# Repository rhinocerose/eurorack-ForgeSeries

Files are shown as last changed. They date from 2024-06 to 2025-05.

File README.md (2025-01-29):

# Voltage Foundry Modular

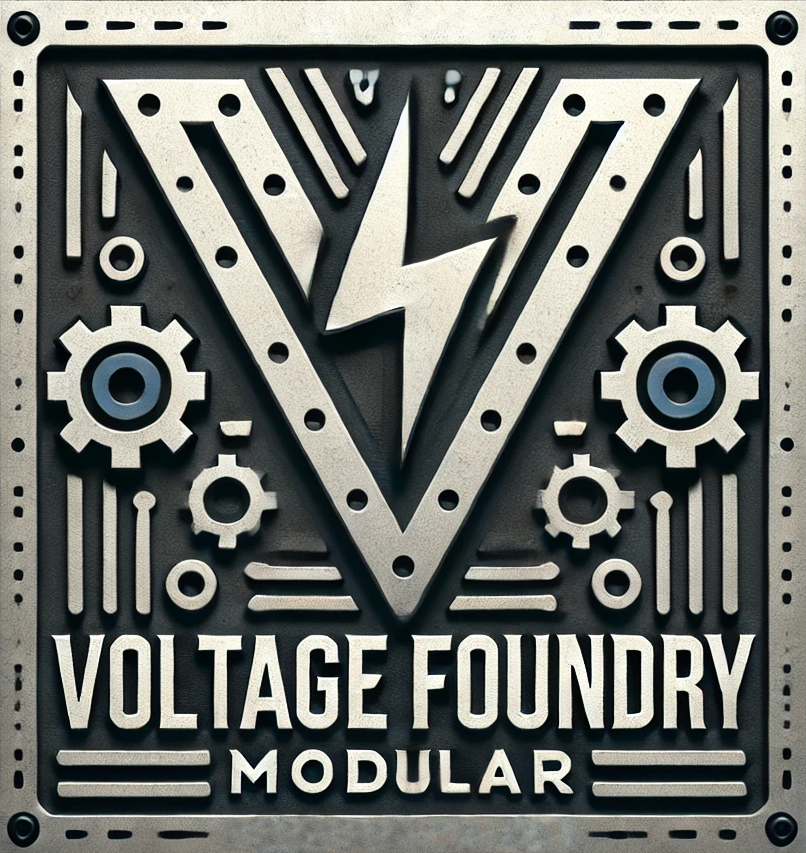
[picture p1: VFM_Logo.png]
Voltage Foundry Modular Logo


This repository hosts the **Forge** series of modules for the Eurorack format. The **Forge** series is a collection of firmwares developed for the Forge V1 platform based on the Seeeduino Xiao and MCP4725 DAC. The modules are designed to be easy to build and modify and be built with through-hole components. The firmware is based on the Arduino platform.

The concept is to have a generic hardware with a display, rotary encoder, trigger inputs and output, CV inputs and outputs allowing different modules by changing the firmware.

The module's core uses a Seeeduino Xiao (SAMD21/Cortex M0 chip) and a MCP4725 DAC.

This project currently provides the following modules:

- [ClockForge](./firmware-CLK/) - A Clock Generator with multiple features like tap tempo, clock division, Euclidean rhythm and more.
- [NoteForge](./firmware-DQ/) - A Dual Quantizer with selectable scales and root notes for each channel, octave shift and envelopes.
- [ForgeView](./firmware-SCP/) - A scope visualizer with dual-trace, trigger and more.

Modules can also be found on ModularGrid:

- [ClockForge](https://modulargrid.net/e/other-unknown-clockforge-by-voltage-foundry-modular)
- [NoteForge](https://modulargrid.net/e/other-unknown-NoteForge-by-voltage-foundry-modular)
- [ForgeView](https://modulargrid.net/e/other-unknown-forgeview-by-voltage-foundry-modular)

Each new module firmware will be in a separate folder which can be built and uploaded to the Seeeduino Xiao using PlatformIO.

## Production specifications

- Eurorack standard 3U 6HP size
- Power supply: 60mA
- Module depth: 42mm
- On-board converter from 12V to internal 5V (jumper selectable)

Power supply can be select from an on-board jumper where closing the the SEL with REG jumper, will take power from eurorack 12V supply and closing the SEL with BOARD jumper, will take power from 5V (requires 16 pin cable). It can also be powered by the USB-C jack on the Seeeduino Xiao.

## Project State

- ✅ - Working
- ❎ - Not tested
- 🚧 - Under development
- ❓ - Works with issues

| Firmware | Works | Remarks |
| --- | ----- | --- |
| Hardware | ✅ | |
| Clock Generator | ✅ | |
| Dual Quantizer | ✅ | |
| Scope | ❓ | Spectrum Analyzer not working yet |
| Dual Sequencer | 🚧 | |
| Sequencer | ❎ | Original firmware, not tested |
| Generative Sequencer | ❎ | Original firmware, not tested |

## Simulations

- Clock Generator: [Link](https://wokwi.com/projects/403851982905059329)

## Hardware and PCB

You can find the schematic and BOM in the [Hardware](./Hardware/) folder.
For the PCBs, the module has one main circuit PCB, one control circuit PCB and one panel PCB. The files are available in the [gerbers](./Hardware/gerbers/) directory.
You can order them on any common PCB manufacturing service, I used [JLCPCB](https://jlcpcb.com/). I made the circuits pcbs under 100mm to get the discount price.

If the panel size is not correctly detected by JLC manually put 30x128.5 mm.

When ordering the display module, make sure to choose an 0.96 I2C oled module that has the pinout specified as GND-VCC-SCL-SDA as opposed to VCC-GND-SCL-SDA (both exist and the latter won't work).

Also make sure you order a Seediuno XIAO (with a SAMD21/Cortex M0 chip) as opposed to the XIAO esp32c3 or the XIAO rp2040, those are different chips.

Display Module

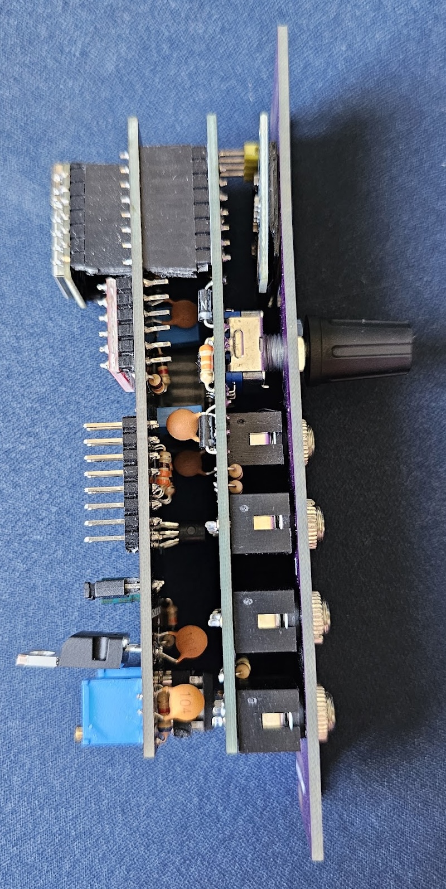
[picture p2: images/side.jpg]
Module Side


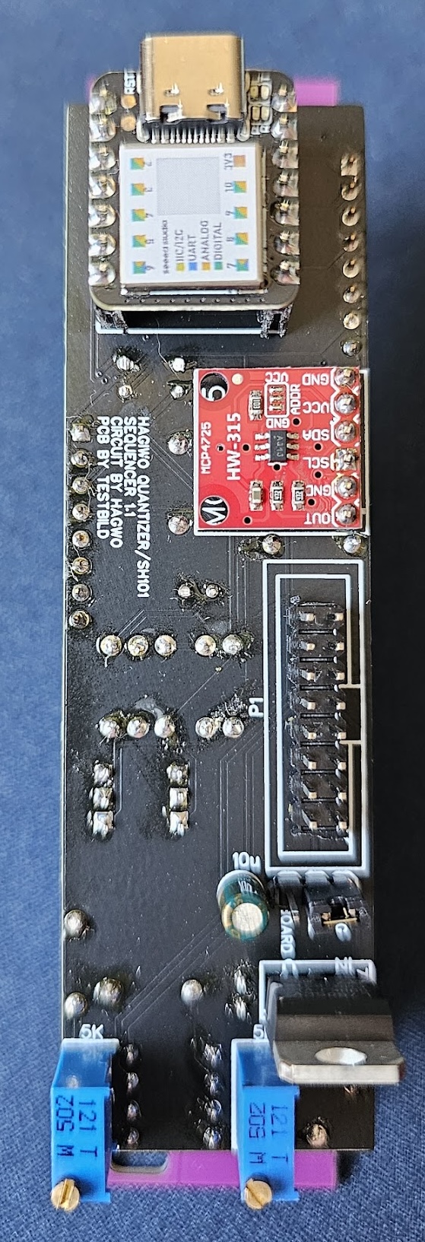
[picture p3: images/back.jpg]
Module Back


Pinout Diagram:

```text
|--------------------|
|                    |
|         O          |    1
|                    |
|   O           O    |  2   3
|                    |
|                    |
|   O           O    |  4   5
|                    |
|   O           O    |  6   7
|                    |
----------------------
```

- 1 - Trigger / Clock Input
- 2 - CV In 1
- 3 - CV In 2
- 4 - Digital Out 1
- 5 - Digital Out 2
- 6 - Analog Out 1 (Internal DAC)
- 7 - Analog Out 2 (External DAC)

## Assembly

When assembling, you can either use a header for the screen or solder it directly, as it is a litte too tall.
The 7805 voltage regulator is optional, if you do not want to use it, simply solder the SEL header on the back of the main pcb to BOARD instead of REG (meaning you bridge the connection to choose your 5v voltage source to either be 12 regulated to 5v, or a 5V connection of your rack power if you have it).

## Calibration

There are two things  in the circuit that need to be tuned for: The input resistor divider going from 5V to 3.3V, and the output opamp gain to go from 3.3 back to 5V.
I will provide a script to help with this and a detailed description in the future, but for now the short version is: Input resistors are compensated for in code with the AD_CH1_calb/AD_CH2_calb parameters. Output gain is adjusted using the trimmers on the main pcb.

Vin(5v) *(R21(33k)/R21(33k)+R19(18k) = Vout
5v:1 = Vout:a(AD_CH1_calb) (in my case AD_CH1_calb = 0.971)

3.3v to 5v(scale up)
5v/3.3v = 1.51515
0.51515 = 5k(adjustable)/6.8k

## Acknowledgements

The initial [hardware](./Hardware/) is based on Hagiwo 033 module. The quantizer base code is from the [original](https://note.com/solder_state/n/nb8b9a2f212a2) Hagiwo 033 Dual Quantizer and the updated thru-hole project by [Testbild-synth](https://github.com/Testbild-synth/HAGIWO-029-033-Eurorack-quantizer). Some ideas for the clock module were "taken" from the [LittleBen module](https://github.com/Quinienl/LittleBen-Firmware) from Quinie.nl and Pamela's Workout.

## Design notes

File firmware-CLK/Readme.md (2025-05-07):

# ClockForge: Crafting Time, One Pulse at a Time

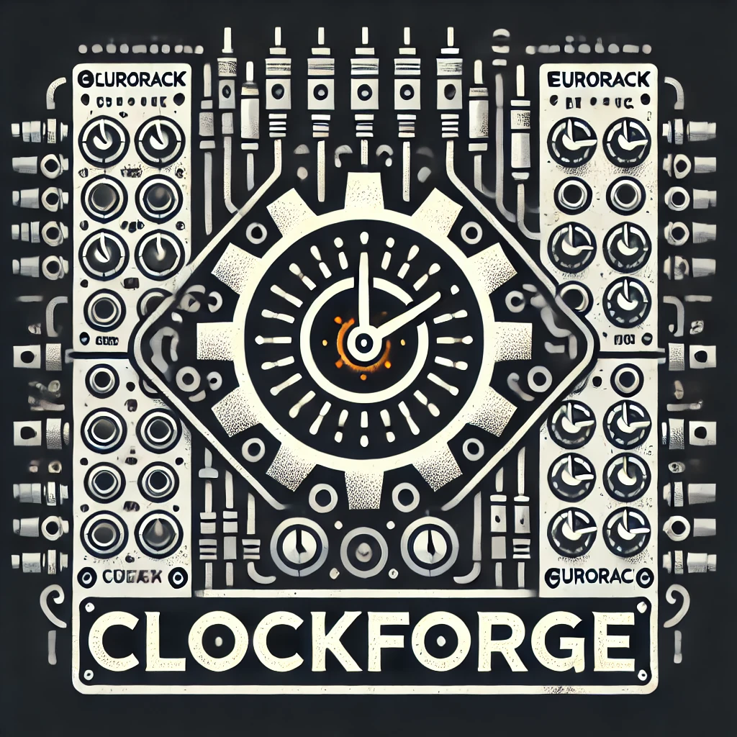
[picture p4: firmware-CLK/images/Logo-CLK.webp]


## Overview

ClockForge provides clock signals and waves for synchronizing and modulating other modules in your Eurorack system. It features a global BPM control, multiple clock outputs, adjustable clock multiplication and division per output, tap tempo functionality, sync to external clock sources, Euclidean rhythm generation, and custom swing patterns per output.

Part of the **Forge** series of modules which share a single hardware platform.

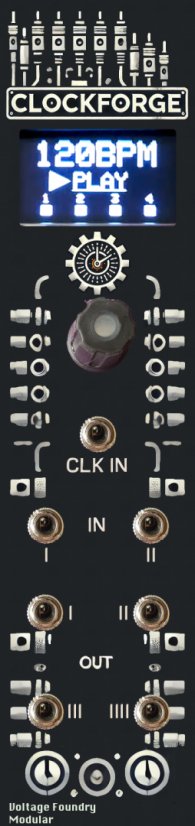
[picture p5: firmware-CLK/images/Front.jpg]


[ModularGrid]([https://](https://modulargrid.net/e/other-unknown-clockforge-by-voltage-foundry-modular))

## Features

- **Global BPM Control**: Set the global BPM for all outputs.
- **Multiple Clock Outputs**: Four clock outputs with individual settings.
- **Adjustable Clock Multiplication and Division**: Configure each output to multiply or divide the global BPM.
- **Output Waveform Generation**: Outputs 3 and 4 can generate different waveforms for modulation.
- **Pulse Probability**: Set the probability of a pulse occurring.
- **Euclidean Rhythm Generation**: Generate complex rhythms using Euclidean algorithm.
- **Custom Swing Patterns**: Apply swing to each output individually.
- **Sync to External Clock Sources**: Automatically adjust BPM based on an external clock signal.
- **Phase Shift**: Adjust the phase of the output in relation to the master clock.
- **Waveform Duty Cycle**: Adjust the pulse width of the clock signal.
- **External modulation**: Many parameters can be modulated by the CV inputs.
- **Tap Tempo Functionality**: Manually set the BPM by tapping a button.
- **Quantization**: Quantize the output wave or CV input to some scale and root note.
- **Save/Load Configuration**: Save and load up to 5 configurations.

## Configuration Parameters

The right side of the screen shows a navigation line to indicate the current position of the cursor in the menu. The navigation is not shown in the main (BPM) screen.

Whenever a parameter is changed, a small circle will be shown in the top-left corner of the screen. This indicates that the current settings were modified and not saved.

Due to encoder reads and screen update, expect some glitches in timing and waveform generation when changing parameters. The module will stabilize right after the parameter is set.

### Global Parameters

- **BPM**: Beats per minute, adjustable from 10 to 300.
- **Master Stop**: Stop or resume all outputs.

The small squares on main screen shows the status of each output. If the square is filled, the output is active. If the square is empty, the output is stopped.

### Output Parameters

Each of the four outputs can be individually configured with the following parameters:

- **Divider/Multiplier**: Set the clock multiplication or division ratio.
- **Output State**: Enable or disable the specific output.
- **Pulse Probability**: Probability of a pulse occurring.
- **Euclidean Enabled**: Enable or disable Euclidean rhythm generation.
- **Euclidean Steps**: Number of steps in the Euclidean pattern.
- **Euclidean Triggers**: Number of triggers in the Euclidean pattern.
- **Euclidean Rotation**: Rotate the Euclidean pattern.
- **Euclidean Pad**: Add empty steps to the end of the Euclidean pattern.
- **Swing Amount**: Adjust the swing amount for the output.
- **Swing Every**: Set the pulse interval for applying swing.
- **Phase Shift**: Adjust the phase of the output in relation to the master clock.
- **Duty Cycle**: Adjust the pulse width of the clock signal.
- **Level**: Set the output voltage level (only for CV outputs 3 and 4).
- **Offset**: Set the output voltage offset (only for CV outputs 3 and 4).
- **Waveform**: Select the waveform for outputs 3 and 4.
- **Quantization**: Quantize the output to a specific scale and root note.

## Operation

### Interface

- TRIG: Optional Clock input (0-5V)
- IN1, IN2: CV input to control internal parameters (0-5V)
- OUT 1 / 2: Clock Outputs 1 and 2 (0-5V)
- OUT 3 / 4: Clock Outputs 3 and 4 which are waveform capable (0-5V)

### Setting the BPM

1. Use the encoder to navigate to the BPM setting.
2. Push the encoder to enter edit mode.
3. Rotate the encoder to adjust the BPM value.
4. Press the encoder to exit edit mode.

### Global Play/Stop

With the **PLAY** or **STOP** word underlined, press the encoder button to stop or resume all outputs. The individual outputs can still be stopped or resumed individually and will remain in the last state set.

### Output clock division/multiplication

Outputs can be configured to multiply or divide the master clock. The default value is 1x which means the output will be in sync with the master clock. The outputs can be multiplied up to 32x or divided down to /128 with some triplets and dotted notes in between in the "1.5" and "3" division and multiplier values.

1. Navigate to the selected output.
2. Click the encoder to enter edit mode.
3. Use the encoder to select the desired divider value.
4. Click the encoder to exit edit mode.

### Output Play/Stop

Outputs can be stopped individually. When stopped, the output will not generate any pulses. When master stop is activated, all outputs will be stopped and when master play is resumed, any stopped output will be kept stopped.

1. Navigate to the selected output.
2. Click the encoder to set the output to ON or OFF

If the output wave type is set to "Play", the output will be true (high) when the master clock is running and false (low) when the master clock is stopped. This is useful for triggering other modules based on the master clock.

If the output wave type is set to "Reset", the output will trigger (high) when the master clock starts running. This is useful for resetting other modules based on the master clock.

### Pulse Probability

This is the percentage of probability that a pulse will be generated on the output. This is useful for creating random patterns or adding some variation to the output.

1. Navigate to the selected output.
2. Click the encoder to enter edit mode.
3. Use the encoder to select the desired pulse probability in percentage.
4. Click the encoder to exit edit mode.

### Euclidean Rhythm Configuration

Euclidean rhythms are made from an algorithm which takes a numbers of steps, triggers(HITS) which are active steps and rotation(RT) of this pattern and produces a rhythm based the on hits being as equidistant from each other as possible. See <https://en.wikipedia.org/wiki/Euclidean_rhythm> for more info.

Additional empty steps can be added to the pattern using the pad(PD) parameter. This is useful for creating more complex rhythms.

1. Navigate to the output selection item. Click the encoder and rotate to select the output to be edited. Click the encoder again to exit the output selection.
2. First setting enables or disables the Euclidean rhythm generation by clicking the encoder.
3. Select the Steps, Triggers and Rotation parameters, click the encoder to edit the values.
4. The pattern will be updated in real-time and displayed on the right of the screen. Euclidean rhythm allows up to 64 steps but only the first 47 are displayed. Rhythm steps are shown in columns, top to bottom, left to right.

The euclidean rhythm pulse is affected by the pulse probability setting.

### Swing Configuration

The outputs can have a swing pattern applied to them. The swing amount is in 1/96th of a note based on current BPM and the swing every is the interval between applying the swing. The swing amount can be set from 2/96th to 12/96th delay and the swing every from 1 to 16 pulses.

1. Navigate to the selected output. The first parameter to be edited is the swing amount.
2. Click the encoder to enter edit mode.
3. Use the encoder to select the desired swing amount.
4. Click the encoder to exit edit mode.
5. Navigate to the selected output, the second parameter to be edited is the swing every.
6. Click the encoder to enter edit mode.
7. Use the encoder to select the desired swing every value.
8. Click the encoder to exit edit mode.

### Output Phase Shift

Outputs can have their phase adjusted in percentage in relation to the master pulse. This allows for phase shifting the output in relation to the master clock. The default value is 0% which means the output is in phase with the master clock.
An adjstment of 50% will shift the output by half a pulse width which means that this output will hit in the upbeats of the master clock (or an output with a 0% phase shift).

Just be careful with phase wraps as shifting an output phase by more than 50% with a duty-cycle bigger than 50% can lead to unexpected triggers.

### Duty Cycle (pulse width)

Duty cycle or width is the percentage of the pulse that remains high or low. The default value is 50% which means the pulse high cycle has the same lenght as the low cycle. The duty cycle can be set from 1 to 99% where 1% will generate a very short pulse and 99% a very long high pulse.

The alternative waveforms generated by outputs 3 and 4 can also have their shape modified by the duty cycle parameter. For example, a 50% duty cycle (default) in the triangle wave output will generate a perfect triangle wave, setting the duty cycle to 1% will generate a sawtooth wave and setting it to 99% will generate an inverted sawtooth wave. The duty cycle also affects the envelopes by shortening or lengthening the decay time during the pulse.

1. Select the duty cycle parameter for the desired output. Click the encoder to enter edit mode.
2. Use the encoder to select the desired duty cycle value from 1 to 99%.
3. Click the encoder to exit edit mode.

### Output Level and Offset

Outputs 3 and 4 can output CV values so they support setting the output level and offset which ranges from 0 to 100% corresponding to 0 to 5V.

1. Navigate to the selected output. Click the encoder to enter edit mode.
2. Use the encoder to select the desired output level from 0 to 100% which corresponds to 0 to 5V.
3. Click the encoder to exit edit mode.

### Output Waveform

Outputs 1 and 2 only support square waveforms which could be used as triggers, gates, clocking, LFOs. etc.

Outputs 3 and 4 can be configured to alternative waveforms and envelopes.

They support the following:

- **Square**: A square wave with adjustable duty cycle, level and offset.
- **Triangle**: A triangle wave with adjustable duty cycle, level and offset.
- **Sawtooth**: A sawtooth wave with adjustable duty cycle, level and offset.
- **Sine**: A sine wave with adjustable duty cycle, level and offset.
- **Parabolic**: A parabolic wave with adjustable duty cycle, level and offset.
- **Logarithm Envelope**: A logarithm envelope (starts at 0% raising to 100%) with adjustable level and offset. Triggered by clock pulses.
- **Exponential Envelope**: An exponential envelope (starts at 0% raising to 100%) with adjustable level and offset. Triggered by clock pulses.
- **Inverted Logarithm Envelope**: An inverted logarithm envelope (starts at 100% decaying to 0) with adjustable level and offset. Triggered by clock pulses.
- **Inverted Exponential Envelope**: An inverted exponential envelope (starts at 100% decaying to 0) with adjustable level and offset. Triggered by clock pulses.
- **Noise**: A random signal with adjustable level and offset. Continuous.
- b: A smooth random signal with adjustable level and offset. Continuous.
- **Sample & Hold**: A sample and hold signal based on noise with adjustable level and offset. Triggered by clock pulses.
- **AD Envelope**: An Attack-Decay envelope (no sustain while gate is held) with adjustable level and offset. Triggered by a CV input.
- **AR Envelope**: An Attack-Release envelope (sustain is held at max level while gate is on) with adjustable level and offset. Triggered by a CV input.
- **ADSR** Envelope: An Attack-Decay-Sustain-Release envelope with adjustable level and offset. Triggered by a CV input.
- **Play**: The output will be true (high) when the master clock is running and false (low) when the master clock is stopped. This is useful for triggering other modules based on the master clock.
- **Reset**: The output will trigger (high) when the master clock starts running. This is useful for resetting other modules based on the master clock.
- **Quantize**: The output will quantize according to the selected scale and root note the CV value that is routed to this input in the CV target configuration.

1. Navigate to the selected output option "Output 3/4 WAV". Click the encoder to enter edit mode.
2. Use the encoder to select the desired waveform. The waveform will be updated in real-time.
3. Click the encoder to exit edit mode.

### Envelopes

The module supports envelope generators for outputs 3 and 4. Refer to the Output Waveform section for more information on the envelope types.

The AD, AR and ADSR envelopes can only be generated by using triggers/gates on the CV inputs. They can have configurable curves between logarithmic, linear and exponential and also allow retriggering while the envelope is still active. The other waveforms (square, sine, etc) cannot be triggered by CV inputs.

To set an envelope generation, follow these steps:

1. Go to the waveform selection like in previous section and choose between "AD Env", "AR Env" or "ADSR Env".
2. Then, go to CV Input target configuration, select which CV input will receive the gate/trigger and assign it to the Output 3/4 Env.

Tip: You can have up to 2 envelopes running at the same time, one for each output receiving a trigger from each of the CV inputs. Each output can have a different envelope type, levels, offsets, curves and retriggering settings.

### Tap Tempo

In addition to setting the BPM manually, the module can be set to the desired BPM by clicking the encoder. The module will calculate the BPM based on the interval between taps.

1. Select the tap tempo parameter.
2. Press the encoder button at least 3 times to set the BPM based on the interval between taps. If more than 3 taps are entered, the average time between the last 3 is used. BPM is updated in real-time.

### CV Input Modulation

Many parameters can be modulated by the CV inputs. The CV inputs are 0-5V and can be used to modulate the BPM, output division/multiplication, pulse probability, swing amount, swing every, phase shift, duty cycle, waveform, level and offset.

Each input can be assigned to one of the parameters above. The CV input can be attenuated or offset by using configuration parameters.

1. Navigate to the selected CV Input parameter.
2. Click the encoder to enter edit mode.
3. Use the encoder to select the desired parameter to be modulated.
4. Click the encoder to exit edit mode.
5. Optionally, navigate to the attenuation and offset parameters for each CV input and set the desired values in a similar way.

The CV target only apply to the selected parameter when the user exit the edit mode. This way a connected CV to an input does not change the scrolled parameters while the user is selecting the target.

### Quantization

The module supports quantization of the output to a specific scale and root note. The quantization can be applied to the output waveform or to the CV input.

The Quantize Settings menu allows you to enable/disable quantization for the selected output, choose the root note, scale to be used and octave transpose with 3 octave levels higher or lower.

To use quantization on the generated output, first select the output waveform type (sine, S&H, etc) and then enable the quantization on Quantize menu. Select the root note and scale to be used. The quantization will be applied to the output waveform.

It's also possible to quantize an input CV signal to a specific scale and root note. This is useful for using CV values generated by external modules. To use quantization on the CV input, choose the "Quantize" waveform type. Then in the Quantize menu, select the root note and scale to be used. Lastly, in the CV Input Targets menu, assign the CV input to the output to be quantized.

Eg. if you want to quantize the CV input 1 to the output 3, select the "Quantize" waveform type for output 3 and then in the CV Input Targets menu, assign CV input 1 to output 3. The quantization will be applied to the output waveform. Also select which scale and root note to be used in the Quantize menu.

### Save/Load Configuration

The module has 5 memory slots to save and load configuration. The parameters saved into slot 0 is automatically loaded on boot.

1. Navigate to the PRESET SLOT parameter.
2. Click the encoder to enter the desired slot selection.
3. Click to exit the slot selection.
4. Select SAVE and click the encoder to save the current slot configuration.
5. Select LOAD and click the encoder to load the selected slot configuration.

The "LOAD DEFAULTS" option will load the default configuration to current parameters but will not save it. To save the default configuration, navigate to the save configuration parameter and save it to the selected preset slot.

### External Clock Sync

1. Connect an external clock signal to the designated input.
2. The module will automatically adjust the BPM to match the external clock. A small "E" will be displayed on the screen next to BPM when the external clock is detected.
3. When the external clock is disconnected, the module will revert to the last used internal BPM.

If the external clock is faster than needed (for example running at higher PPQN), it's possible to apply an external clock divider (from 1x, no division to /16) to the input signal in the Clock Divider section.

The module works with external clocks from 30 to 300 BPM. Due to timer resolution, using very slow external clocks with high multipliers may lead to jitter on the outputs.

## Firmware Update

1. Download the latest firmware from the Releases section of the [GitHub repository](https://github.com/VoltageFoundryMod/ForgeSeries/releases). The firmware file is named `CURRENT.UF2`.
2. Connect the module to your computer using a USB-C cable. The CPU can be removed from the module as it's socketed to the main board. Firmware loading can be done with the CPU removed.
3. Use tweezers or a jumper wire to quickly short TWICE the two pads labeled `RESET` on the back of the module CPU. The orange LED will flicker and light up.
4. Copy and overwrite the `CURRENT.UF2` file to the module USB drive named "Seeed XIAO" that will appear. After copy is finished, the module will reboot and the new firmware will be loaded.

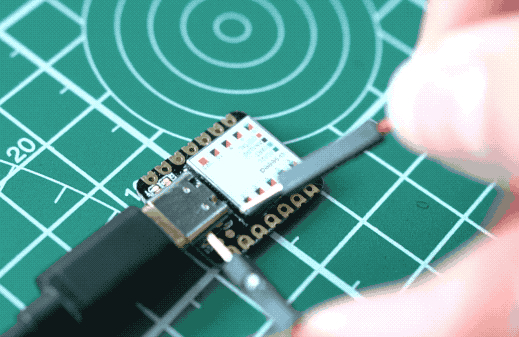
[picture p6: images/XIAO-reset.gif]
Module bootloader mode


## Troubleshooting

- **No Power**: Ensure the module is properly connected to the power supply and the power jumper is set correctly.
- **No Output**: Verify the board connections and output settings and ensure the module is not stopped.
- **Inconsistent BPM**: Ensure the external clock signal is stable and properly connected.

## Powering

The module can be powered by either 12V or 5V if your power supply supports it. The supply can be selected from an on-board jumper where closing the the SEL with REG jumper, will take power from eurorack 12V supply and closing the SEL with BOARD jumper, will take power from 5V (requires 16 pin cable). It can also be powered by the USB-C jack on the Seeeduino Xiao.

## Specifications

- **Power Supply**: 12V or 5V jumper selectable
- **Input CV Range**: 5V
- **Output CV Range**: 5V
- **Dimensions**: 6HP
- **Depth**: 40mm
- **Current Draw**: 60mA @ +12V or +5V

## Contact

For support and inquiries, please open an issue on the [GitHub repository](https://github.com/VoltageFoundryMod/ForgeSeries).

## Development

If you want to build and developt for the module, check [this file](Building-Developing.md) for more information.

## Acknowledgements

Parts of the code are inspired by Hagiwo code, Quinienl's [LittleBen](https://github.com/Quinienl/LittleBen-Firmware) and Pamela's Workout.
Thanks for the inspiration!

## License

This project is licensed under the MIT License. See the `LICENSE` file for more information.

---

Thank you for choosing the ClockForge module. We hope it enhances your musical creativity and performance.

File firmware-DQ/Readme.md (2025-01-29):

# NoteForge - A Dual Quantizer Eurorack Module

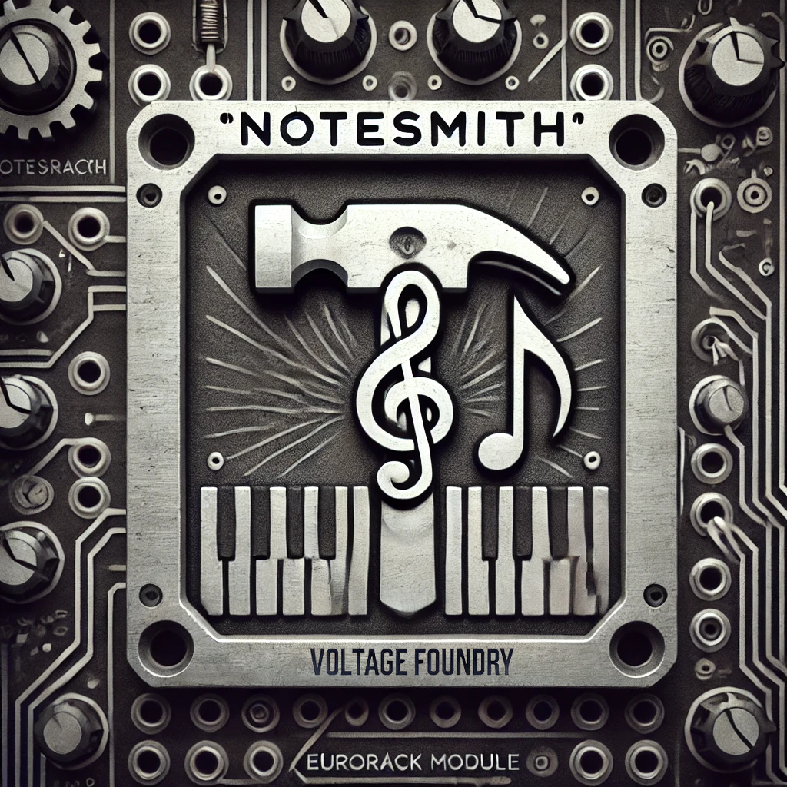
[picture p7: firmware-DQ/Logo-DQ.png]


## Introduction

NoteForge is a versatile tool designed to quantize analog control voltages (CV) into musical notes. It features two independent quantizers, each capable of processing input CV signals and outputting quantized CV signals corresponding to musical notes. The module supports various scales and allows for customization of attack and decay envelopes, sync modes, octave shifts, and sensitivity settings.

Part of the **Forge** series of modules which share a single hardware platform.

## Features

- Two independent quantizers
- Support for multiple scales
- Customizable attack and decay envelopes
- Sync modes on trigger and note change
- 3 Octave shift and sensitivity settings
- OLED display for easy configuration
- Rotary encoder for menu navigation and parameter adjustment

## Getting Started

### Powering the Module

1. Connect the module to a suitable power source.
2. Ensure that the power supply provides the correct voltage and current requirements.

### Initial Setup

1. Power on the module.
2. The OLED display will show a splash screen followed by the module name and version number.
3. Module will load default parameters for scale, root note and envelope/octave settings.

### Interface

- TRIG: Trigger input (0-5V)
- IN1, IN2: CV input to be quantized (0-5V)
- GATE 1 / 2: Gate with envelope curve output for each channel (0-5V)
- CV 1 / 2: CV output with quantized scale output for each channel (CH1: 10bit, CH2: 12bit, 0-5V)

## Menu Navigation

### Rotary Encoder

- **Rotate Clockwise**: Increase the selected parameter or navigate to the next menu item.
- **Rotate Counter-Clockwise**: Decrease the selected parameter or navigate to the previous menu item.
- **Press**: Enter item edit mode or confirm changes.

### Menu Structure

1. **Scale Selection**
   - Select the desired musical scale for each quantizer.
2. **Root Note Selection**
   - Select the root note for the chosen scale.
3. **Attack Envelope**
   - Adjust the attack time for each quantizer.
4. **Decay Envelope**
   - Adjust the decay time for each quantizer.
5. **Sync Mode**
   - Choose between trigger sync and note change sync for each quantizer.
6. **Octave Shift**
   - Adjust the octave shift for each quantizer.
7. **Sensitivity**
   - Adjust the sensitivity of the input CV for each quantizer.
8. **Save Settings**
   - Save the current settings to flash memory.

## Detailed Operation

Most parameters can be either clicked to toggle enable/disable or clicked to be selected and rotated to adjust the value. The OLED display will show the current value and the parameter name. An empty arrow will indicate that the parameter is selected and a filled arrow will indicate that the parameter is being edited.

### Scale and Root Note Selection

1. Navigate to the "Scale" menu item.
2. Rotate the encoder to select the desired scale.
3. Press the encoder to confirm the selection.
4. Navigate to the "Root Note" menu item.
5. Rotate the encoder to select the desired root note.
6. Press the encoder to confirm the selection.
7. Load the chosen scale and root note to the 1 or 2 by using the "LOAD IN CH1" or "LOAD IN CH2" menu items.

### Attack and Decay Envelopes

1. Navigate to the "ATK" or "DCY" menu items.
2. Press the encoder to enter edit mode.
3. Rotate the encoder to adjust the attack time.
4. Press the encoder to confirm the selection.

### Sync Mode

1. Navigate to the "Sync Mode" menu item.
2. Click the encoder to choose between trigger sync and note change sync.

### Octave Shift

1. Navigate to the "Octave Shift" menu item.
2. Click to enter edit mode.
3. Rotate the encoder to adjust the octave shift.
4. Press the encoder to confirm the selection.

### Sensitivity

1. Navigate to the "Sensitivity" menu item.
2. Click to enter edit mode.
3. Rotate the encoder to adjust the sensitivity of the input CV.
4. Press the encoder to confirm the selection.

### Saving Settings

1. Navigate to the "Save Settings" menu item.
2. Press the encoder to save the current settings to flash memory.
3. The display will show a "SAVED" message to confirm the operation.

## Calibration

The module requires calibration to properly quantize the input CV signals. The calibration process involves setting the minimum and maximum values for the input CV range.

To enter calibration mode, power on the module while holding the encoder button. The display will guide you through the calibration process. Input 0V (C1) and 5V(C6) from a CV source like a keyboard or sequencer and press the encoder to confirm the values. The module will save the calibration settings to flash memory.

It's required to re-calibrate the module everytime the firmware is updated.

## Firmware Update

1. Download the latest firmware from the Releases section of the [GitHub repository](https://github.com/VoltageFoundryMod/ForgeSeries/releases). The firmware file is named `CURRENT.UF2`.
2. Connect the module to your computer using a USB-C cable. The CPU can be removed from the module as it's socketed to the main board. Firmware loading can be done with the CPU removed.
3. Use tweezers or a jumper wire to quickly short TWICE the two pads labeled `RESET` on the back of the module CPU. The orange LED will flicker and light up.
4. Copy and overwrite the `CURRENT.UF2` file to the module USB drive named "Seeed XIAO" that will appear. After copy is finished, the module will reboot and the new firmware will be loaded.

Module bootloader mode

## Troubleshooting

- **No Power**: Ensure the module is properly connected to the power supply and the power jumper is set correctly.
- **No Output**: Verify the board connections and output settings and ensure the module is not stopped.
- **Inconsistent BPM**: Ensure the external clock signal is stable and properly connected.

### No Output CV

- Ensure that the input CV is within the acceptable range.
- Verify that the correct scale and root note are selected.

## Powering

The module can be powered by either 12V or 5V if your power supply supports it. The supply can be selected from an on-board jumper where closing the the SEL with REG jumper, will take power from eurorack 12V supply and closing the SEL with BOARD jumper, will take power from 5V (requires 16 pin cable). It can also be powered by the USB-C jack on the Seeeduino Xiao.

## Specifications

- **Power Supply**: 12V or 5V jumper selectable
- **Input CV Range**: 5V
- **Output CV Range**: 5V
- **Dimensions**: 6HP
- **Depth**: 40mm
- **Current Draw**: 60mA @ +12V or +5V

## Contact

For support and inquiries, please open an issue on the [GitHub repository](https://github.com/VoltageFoundryMod/ForgeSeries).

## Development

If you want to build and developt for the module, check [this file](Building-Developing.md) for more information.

## License

This project is licensed under the MIT License. See the `LICENSE` file for more information.

---

Thank you for choosing the Dual Quantizer module. We hope it enhances your musical creativity and performance.

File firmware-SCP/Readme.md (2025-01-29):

# ForgeView: A scope for Eurorack

<!-- <img src="./images/Logo-CLK.webp" alt="Logo" style="width:50%"/> -->

## Overview

ForgeView provides a simple oscilloscope for Eurorack systems. It can be used to visualize waveforms and signals in your modular system. The module has a 0.96" OLED display and can be used to visualize waveforms from LFOs, envelopes, oscillators, filters, and other signals in your system.

Part of the **Forge** series of modules which share a single hardware platform.

<!-- <img src="./images/Front.jpg" alt="Logo" style="width:20%"/> -->

[ModularGrid](https://modulargrid.net/e/modules/view/52717)

## Features

- **4 modes of operation** - The module can display dual waveforms, single waveform in audio range, single waveform with external trigger and spectrum analyzer.
- **Dual Waveform Display** - Display two waveforms at the same time with configuration for vertical and horizontal scaling and vertical offset.
- **Single Audio Waveform** - Display a single waveform in audio range with configuration for vertical and horizontal scaling and vertical offset.
- **Single Waveform with External Trigger** - Display a single waveform with external trigger input to freeze the waveform like taking a snapshot of a drum hit.
- **Spectrum Analyzer** - Display a spectrum analyzer of the input signal (not implemented yet).

## Configuration Parameters

The display will show the full waveform of the input signals. When the encoder is turned, a menu will show up and the parameters can be adjusted. The parameters are:

- **Mode**: Select the display mode (Dual, Single Audio, Single with Trigger, Spectrum Analyzer).
- **Hori**: Horizontal scaling of the waveform.
- **Offs**: Vertical offset of the waveform.
- **Vert**: Vertical scaling of the waveform.

On dual mode, both traces are scaled and offset together. On single mode, the waveform is scaled and offset individually. This might be improved in the future.

## Operation

### Interface

- TRIG: External trigger input for mode 3 (0-5V)
- IN1, IN2: CV inputs for signals (0-5V)
- OUT 1 / 2: Outputs 1 and 2 (0-5V)
- OUT 3 / 4: Outputs 3 and 4 (0-5V)

The signals from IN1 will be copied in a S&H to OUT1 and the signals from IN2 will be copied in a S&H to OUT2. The signals from IN1 and IN2 will be displayed on the screen. Do not expect high resolution and accuracy on the outputs or the display. The module is intended for visualization and not for high precision measurements.

## Firmware Update

1. Download the latest firmware from the Releases section of the [GitHub repository](https://github.com/VoltageFoundryMod/ForgeSeries/releases). The firmware file is named `CURRENT.UF2`.
2. Connect the module to your computer using a USB-C cable. The CPU can be removed from the module as it's socketed to the main board. Firmware loading can be done with the CPU removed.
3. Use tweezers or a jumper wire to quickly short TWICE the two pads labeled `RESET` on the back of the module CPU. The orange LED will flicker and light up.
4. Copy and overwrite the `CURRENT.UF2` file to the module USB drive named "Seeed XIAO" that will appear. After copy is finished, the module will reboot and the new firmware will be loaded.

Module bootloader mode

## Troubleshooting

- **No Power**: Ensure the module is properly connected to the power supply and the power jumper is set correctly.
- **No Output**: Verify the board connections and output settings and ensure the module is not stopped.

## Powering

The module can be powered by either 12V or 5V if your power supply supports it. The supply can be selected from an on-board jumper where closing the the SEL with REG jumper, will take power from eurorack 12V supply and closing the SEL with BOARD jumper, will take power from 5V (requires 16 pin cable). It can also be powered by the USB-C jack on the Seeeduino Xiao.

## Specifications

- **Power Supply**: 12V or 5V jumper selectable
- **Input CV Range**: 5V
- **Output CV Range**: 5V
- **Dimensions**: 6HP
- **Depth**: 40mm
- **Current Draw**: 60mA @ +12V or +5V

## Contact

For support and inquiries, please open an issue on the [GitHub repository](https://github.com/VoltageFoundryMod/ForgeSeries).

## Development

If you want to build and developt for the module, check [this file](Building-Developing.md) for more information.

## Acknowledgements

Great part of the code are inspired by Hagiwo's code.
Thanks for the inspiration!

## License

This project is licensed under the MIT License. See the `LICENSE` file for more information.

---

Thank you for choosing the ForgeView module. We hope it enhances your musical creativity and performance.

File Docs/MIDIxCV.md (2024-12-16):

# Table for MIDI Note vs CV for 0-5V Scale

| Note | CV Voltage | Frequency (Hz) |
| --- | --- | --- |
| **C1** | 0V | 65.41Hz |
| C#1 | 0.0833V | 69.30Hz |
| D1 | 0.1667V | 73.42Hz |
| D#1 | 0.25V | 77.78Hz |
| E1 | 0.3333V | 82.41Hz |
| F1 | 0.4167V | 87.31Hz |
| F#1 | 0.5V | 92.50Hz |
| G1 | 0.5833V | 98.00Hz |
| G#1 | 0.6667V | 103.83Hz |
| A1 | 0.75V | 110.00Hz |
| A#1 | 0.8333V | 116.54Hz |
| B1 | 0.9167V | 123.47Hz |
| **C2** | 1V | 130.81Hz |
| C#2 | 1.0833V | 138.59Hz |
| D2 | 1.1667V | 146.83Hz |
| D#2 | 1.25V | 155.56Hz |
| E2 | 1.3333V | 164.81Hz |
| F2 | 1.4167V | 174.61Hz |
| F#2 | 1.5V | 185.00Hz |
| G2 | 1.5833V | 196.00Hz |
| G#2 | 1.6667V | 207.65Hz |
| A2 | 1.75V | 220.00Hz |
| A#2 | 1.8333V | 233.08Hz |
| B2 | 1.9167V | 246.94Hz |
| **C3** | 2V | 261.63Hz |
| C#3 | 2.0833V | 277.18Hz |
| D3 | 2.1667V | 293.66Hz |
| D#3 | 2.25V | 311.13Hz |
| E3 | 2.3333V | 329.63Hz |
| F3 | 2.4167V | 349.23Hz |
| F#3 | 2.5V | 369.99Hz |
| G3 | 2.5833V | 392.00Hz |
| G#3 | 2.6667V | 415.30Hz |
| A3 | 2.75V | 440.00Hz |
| A#3 | 2.8333V | 466.16Hz |
| B3 | 2.9167V | 493.88Hz |
| **C4** | 3V | 523.25Hz |
| C#4 | 3.0833V | 554.37Hz |
| D4 | 3.1667V | 587.33Hz |
| D#4 | 3.25V | 622.25Hz |
| E4 | 3.3333V | 659.25Hz |
| F4 | 3.4167V | 698.46Hz |
| F#4 | 3.5V | 739.99Hz |
| G4 | 3.5833V | 783.99Hz |
| G#4 | 3.6667V | 830.61Hz |
| A4 | 3.75V | 880.00Hz |
| A#4 | 3.8333V | 932.33Hz |
| B4 | 3.9167V | 987.77Hz |
| **C5** | 4V | 1046.50Hz |
| C#5 | 4.0833V | 1108.73Hz |
| D5 | 4.1667V | 1174.66Hz |
| D#5 | 4.25V | 1244.51Hz |
| E5 | 4.3333V | 1318.51Hz |
| F5 | 4.4167V | 1396.91Hz |
| F#5 | 4.5V | 1479.98Hz |
| G5 | 4.5833V | 1567.98Hz |
| G#5 | 4.6667V | 1661.22Hz |
| A5 | 4.75V | 1760.00Hz |
| A#5 | 4.8333V | 1864.66Hz |
| B5 | 4.9167V | 1975.53Hz |
| **C6** | 5V | 2093.00Hz |

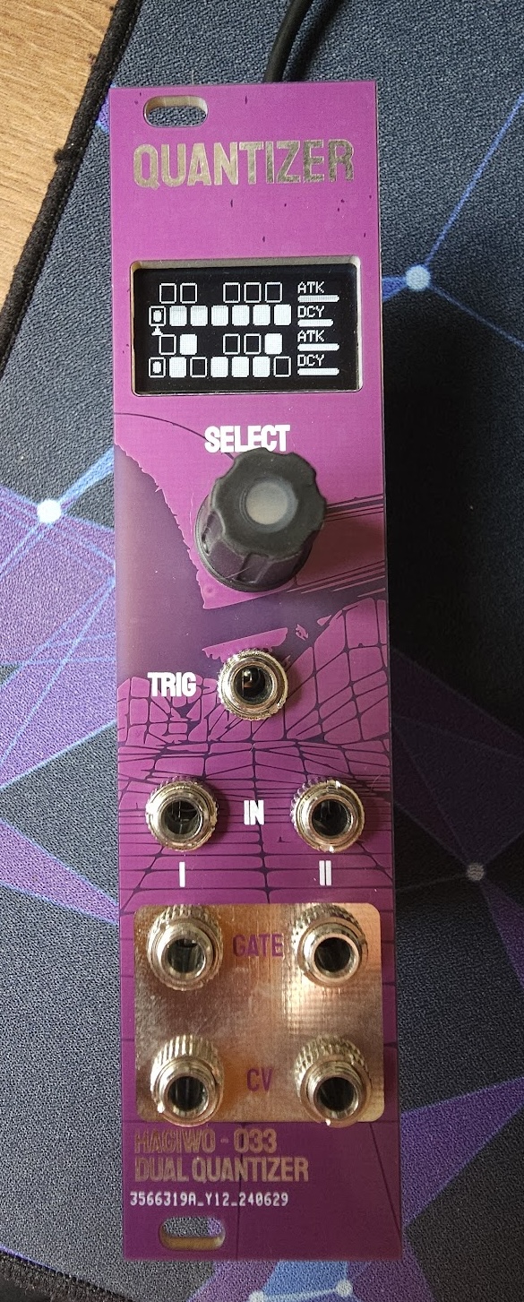
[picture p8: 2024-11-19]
images/Quantizer.jpg

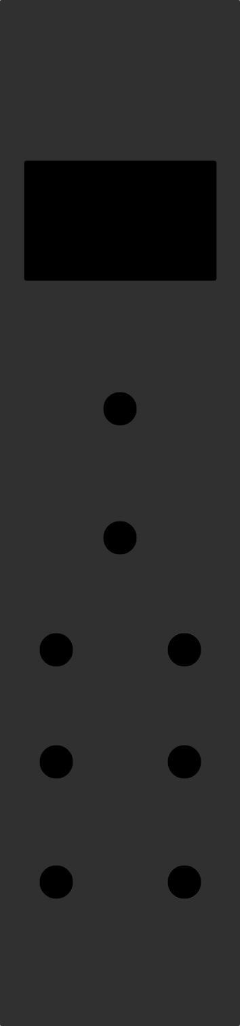
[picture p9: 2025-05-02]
images/BlankPanel_Template.png

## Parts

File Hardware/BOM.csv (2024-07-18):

Name | Designator | Footprint | Quantity
330 | R10,R11,R4,R5 | R_AXIAL-0.3 | 4
470 | R13,R20 | R_AXIAL-0.3 | 2
1k | R6,R12 | R_AXIAL-0.3 | 2
3k3 | R16,R17 | R_AXIAL-0.3 | 2
6.8k | R8,R2 | R_AXIAL-0.3 | 2
5k | R9,R3 | TRIMPOT-VERTICAL | 2
10k | R7,R1 | R_AXIAL-0.3 | 2
18k | R14,R19 | R_AXIAL-0.3 | 2
33k | R15,R21,R18 | R_AXIAL-0.3 | 3
10n ceramic | C7,C8,C9,C10 | RAD-0.1 | 4
470n ceramic | C1,C4 | RAD-0.1 | 2
100n ceramic | C2,C5,C6 | RAD-0.1 | 3
10u electrolytic | C3 | CAP-D4.0×F1.5 | 1
BAT43 | D1,D2,D3,D4,D5,D6 | D_DO-35_SOD27_P7.62MM_HORIZONTAL | 6
BC547A | Q1,Q2 | TO92-INLINE | 2
MCP6002-EP | U1 | DIP8 | 1
MCP4725 Breakout | CN1 | MCP4725-B | 1
7805 Voltage regulator | U3 | 7805 | 1
ALPS_ENCODER+PUSHSWITCH | ENC |  | 1
Seeeduino XIAO (SAMD21) | SEEDUINO | SEEDUINO XIAO | 1
THONKICONN JACK | J1-J7 |  | 7
POWER HEADER | P1 | HDR-IDC-2.54-2X8P | 1
Header-Male-2.54_1x8 | H1,H2 | HDR-TH_8P-P2.54-V-M | 2

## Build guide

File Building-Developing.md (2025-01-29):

## Getting Started

If you want to build the module, check the [main repository](https://github.com/VoltageFoundryMod/ForgeSeries) where the schematics and PCBs are available.

### Prerequisites

Assembly of the DIY module with PCBs, BOM and Schematic from the main repository.

### Installation

1. Clone the repository:

    ```sh
    git clone https://github.com/VoltageFoundryMod/ForgeSeries
    ```

2. Navigate to the project directory:

    ```sh
    cd firmware-???
    ```

3. Open the project using VSCode and PlatformIO extension

4. Build and upload the firmware to the module.

## Contributing

All contributions are welcome, open an issue for questions/problems or a pull request to contribute.

## License

This project is licensed under the MIT License. See the `LICENSE` file for more information.

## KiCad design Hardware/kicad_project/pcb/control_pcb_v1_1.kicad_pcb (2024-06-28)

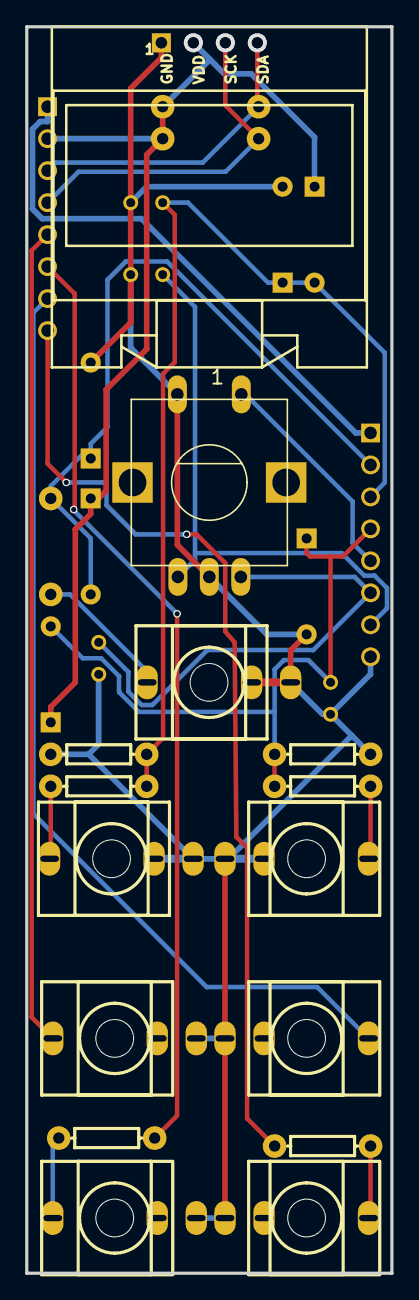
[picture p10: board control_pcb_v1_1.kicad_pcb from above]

Board: 2 copper layers, 29.0 x 99.0 mm, 29 parts (0 on the bottom side), 20 nets.

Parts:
1: ALPS_ENCODER+PUSHSWITCHNORMAL; ENCODER+SWITCH
C7, C8, C9, C10: 10n; RAD-0.1
D1, D2, D3, D4, D5, D6: BAT43; D_DO-35_SOD27_P7.62MM_HORIZONTAL
H1, H2: Header-Male-2.54_1x8; HDR-TH_8P-P2.54-V-M
J1: O4; THONKICONN_1
J2: IN3; THONKICONN_1
J3: O1; THONKICONN_1
J4: IN1; THONKICONN_1
J5: IN2; THONKICONN_1
J6: O2; THONKICONN_1
J7: O3; THONKICONN_1
R13, R20: 470; R_AXIAL-0.3
R14, R19: 18k; R_AXIAL-0.3
R15, R18, R21: 33k; R_AXIAL-0.3
R16, R17: 3k3; R_AXIAL-0.3

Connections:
5V: H1.1, H2.1
ARD_3: D1.1, D3.1, D4.1, H2.2, R16.1, R17.1
ENC_1: 1.B, C8.2, H1.6
ENC_2: 1.A, C9.1, H1.7
ENC_SW: 1.E, H1.5
GND: 1.C, 1.D, C7.1, C8.1, C9.2, C10.1, D2.2, D5.2, D6.2, H1.8, J1.1, J2.1, J2.2, J3.1, J4.1, J4.2, J5.1, J5.2, J6.1, J7.1, R15.2, R21.2
IN_1: D3.2, D5.1, H1.2, R18.1
IN_2: C10.2, D4.2, D6.1, H1.3, R19.1, R21.1
IN_3: C7.2, D1.2, D2.1, H1.4, R14.1, R15.1
J1_3: J1.3, R13.2
J5_3: J5.3, R19.2
J6_3: J6.3, R20.2
O1_CON: H2.5, J3.3
O2_CON: H2.6, R20.1
O3_CON: H2.7, J7.3
O4_CON: H2.8, R13.1
R14_2: J2.3, R14.2
R18_2: J4.3, R18.2
SCL: H2.4, R17.2
SDA: H2.3, R16.2

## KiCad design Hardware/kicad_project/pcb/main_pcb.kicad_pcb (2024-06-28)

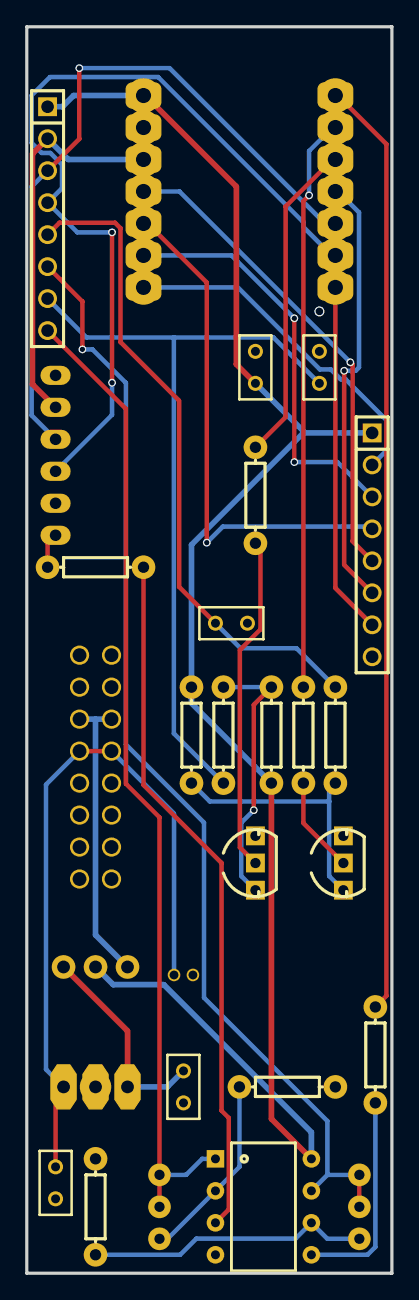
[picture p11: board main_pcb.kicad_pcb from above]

Board: 2 copper layers, 29.0 x 99.0 mm, 28 parts (0 on the bottom side), 30 nets.

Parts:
C1, C4: 470n; RAD-0.1
C2, C5, C6: 100n; RAD-0.1
C3: 10u; CAP-D4.0×F1.5
CN1: MCP4725-B
H4, H5: Header-Male-2.54_1x8; HDR-TH_8P-P2.54-V-M
P1: PWR; HDR-IDC-2.54-2X8P
Q1, Q2: BC547A; TO92-INLINE
R1, R7: 10k; R_AXIAL-0.3
R2, R8: 6.8k; R_AXIAL-0.3
R3, R9: 5K; TRIMPOT-ELETROCURSOS-FOOTPRINT
R4, R5, R10, R11: 330; R_AXIAL-0.3
R6, R12: 1k; R_AXIAL-0.3
SEEDUINO: Seeeduino XIAO; SEEDUINO XIAO
SEL: M03PTH; 1X03
U1: MCP6002-EP; DIP8
U3: 7805

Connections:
5V: C2.2, H4.1, H5.1, R4.2, R10.2, SEEDUINO.14, SEL.2, U1.8
ARD_3: CN1.5, H5.2, SEEDUINO.12
CN1_1: CN1.1, R1.1
ENC_1: H4.6, SEEDUINO.4
ENC_2: H4.7, SEEDUINO.7
ENC_SW: H4.5, SEEDUINO.11
GND: C1.2, C2.1, C3.2, C4.2, C5.1, C6.2, CN1.2, CN1.6, H4.8, P1.3, P1.4, P1.5, P1.6, P1.7, P1.8, Q1.3, Q2.3, R2.1, R8.1, SEEDUINO.13, U1.4, U3.2
IN_1: H4.2, SEEDUINO.8
IN_2: H4.3, SEEDUINO.9
IN_3: H4.4, SEEDUINO.10
O1: R6.1, SEEDUINO.2
O1_CON: C1.1, H5.5, R5.1
O2: R7.1, SEEDUINO.1
O2_CON: H5.6, R9.2, R9.3, U1.7
O3: R12.1, SEEDUINO.3
O3_CON: C4.1, H5.7, R11.1
O4_CON: H5.8, R3.2, R3.3, U1.1
P1_10: C3.1, C5.2, P1.9, P1.10, U3.1
POW_5: P1.11, P1.12, SEL.3
Q1_1: Q1.1, R4.1, R5.2
Q2_1: Q2.1, R10.1, R11.2
R1_2: R1.2, U1.3
R2_2: R2.2, R3.1, U1.2
R6_2: Q1.2, R6.2
R7_2: R7.2, U1.5
R9_1: R8.2, R9.1, U1.6
R12_2: Q2.2, R12.2
REG_5: C6.1, SEL.1, U3.3
SCL: CN1.3, H5.4, SEEDUINO.6
SDA: CN1.4, H5.3, SEEDUINO.5

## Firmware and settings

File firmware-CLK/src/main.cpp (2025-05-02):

#include <Arduino.h>
#include <TimerTCC0.h>
// Rotary encoder setting
#define ENCODER_OPTIMIZE_INTERRUPTS
#include <Encoder.h>

#include <Adafruit_GFX.h>
#include <Adafruit_SSD1306.h>
#include <Wire.h>

// Load local libraries
#include "boardIO.hpp"
#include "loadsave.hpp"
#include "outputs.hpp"
#include "pinouts.hpp"
#include "splash.hpp"
#include "utils.hpp"
#include "version.hpp"

// ADC Calibration settings
const int ADC_THRESHOLD = 5;        // Threshold for ADC stability
float ADCCal[2] = {1.0180, 1.0180}; // ADC readings for the channels
int ADCOffset[2] = {23, 23};        // ADC offset for the channels

// Configuration
#define PPQN 192
#define MAXDAC 4095

#define OLED_ADDRESS 0x3C
#define SCREEN_WIDTH 128
#define SCREEN_HEIGHT 64

// OLED display object
Adafruit_SSD1306 display(SCREEN_WIDTH, SCREEN_HEIGHT, &Wire, -1);

// Rotary encoder object
Encoder encoder(ENC_PIN_1, ENC_PIN_2); // rotary encoder library setting
float oldPosition = -999;              // rotary encoder library setting
float newPosition = -999;              // rotary encoder library setting

// Output objects
Output outputs[NUM_OUTPUTS] = {
    Output(1, OutputType::DigitalOut),
    Output(2, OutputType::DigitalOut),
    Output(3, OutputType::DACOut),
    Output(4, OutputType::DACOut)};

// ---- Global variables ----

// CV modulation targets
enum CVTarget {
    None = 0,
    StartStop,
    Reset,
    SetBPM,
    Div1,
    Div2,
    Div3,
    Div4,
    Output1Prob,
    Output2Prob,
    Output3Prob,
    Output4Prob,
    Swing1Amount,
    Swing1Every,
    Swing2Amount,
    Swing2Every,
    Swing3Amount,
    Swing3Every,
    Swing4Amount,
    Swing4Every,
    Output3Level,
    Output4Level,
    Output3Offset,
    Output4Offset,
    Output3Waveform,
    Output4Waveform,
    Output1Duty,
    Output2Duty,
    Output3Duty,
    Output4Duty,
    Envelope1,
    Envelope2,
    Output3,
    Output4,
};

String CVTargetDescription[] = {
    "None",
    "Start/Stop",
    "Reset",
    "Set BPM",
    "Output 1 Div",
    "Output 2 Div",
    "Output 3 Div",
    "Output 4 Div",
    "Output 1 Prob",
    "Output 2 Prob",
    "Output 3 Prob",
    "Output 4 Prob",
    "Swing 1 Amt",
    "Swing 1 Every",
    "Swing 2 Amt",
    "Swing 2 Every",
    "Swing 3 Amt",
    "Swing 3 Every",
    "Swing 4 Amt",
    "Swing 4 Every",
    "Output 3 Lvl",
    "Output 4 Lvl",
    "Output 3 Off",
    "Output 4 Off",
    "Output 3 Wav",
    "Output 4 Wav",
    "Output 1 Duty",
    "Output 2 Duty",
    "Output 3 Duty",
    "Output 4 Duty",
    "Output 3 Env",
    "Output 4 Env",
    "Output 3",
    "Output 4",
};
int CVTargetLength = sizeof(CVTargetDescription) / sizeof(CVTargetDescription[0]);
CVTarget pendingCVInputTarget[NUM_CV_INS] = {CVTarget::None, CVTarget::None};

// ADC input offset and scale from calibration
float offsetScale[NUM_CV_INS][2]; // [channel][0: offset, 1: scale]
// CV target settings
CVTarget CVInputTarget[NUM_CV_INS] = {CVTarget::None, CVTarget::None};
int CVInputAttenuation[NUM_CV_INS] = {0, 0};
int CVInputOffset[NUM_CV_INS] = {0, 0};

// ADC input variables
float channelADC[NUM_CV_INS], oldChannelADC[NUM_CV_INS];

// BPM and clock settings
unsigned int BPM = 120;
unsigned int lastInternalBPM = 120;
unsigned int const minBPM = 10;
unsigned int const maxBPM = 300;

// Play/Stop state
bool masterState = true; // Track global play/stop state (true = playing, false = stopped)

// Global tick counter
volatile unsigned long tickCounter = 0;

// External clock variables
volatile unsigned long clockInterval = 0;
volatile unsigned long lastClockInterruptTime = 0;
volatile bool usingExternalClock = false;

static int const dividerAmount = 7;
int externalClockDividers[dividerAmount] = {1, 2, 4, 8, 16, 24, 48};
String externalDividerDescription[dividerAmount] = {"x1", "/2 ", "/4", "/8", "/16", "24PPQN", "48PPQN"};
int externalDividerIndex = 0;
volatile unsigned long externalTickCounter = 0;

unsigned long lastDisplayUpdateTime = 0;
const unsigned long DISPLAY_UPDATE_INTERVAL = 50; // Minimum 50ms between display updates
uint8_t frameSkip = 0;
const uint8_t FRAME_SKIP_COUNT = 3; // Only update every 4th request

// Menu variables
int menuItems = 66;
int menuItem = 3;
bool switchState = 1;
bool oldSwitchState = 1;
int menuMode = 0;                    // Menu mode for parameter editing
bool displayRefresh = 1;             // Display refresh flag
bool unsavedChanges = false;         // Unsaved changes flag
int euclideanOutputSelect = 0;       // Euclidean rhythm output index
int quantizerOutputSelect = 2;       // Quantizer output index
int envelopeOutputSelect = 2;        // Envelope output index
int saveSlot = 0;                    // Save slot index
unsigned long lastEncoderUpdate = 0; // Last encoder update time

// Function prototypes
void UpdateBPM(unsigned int);
void SetTapTempo();
void HandleIO();
void SetMasterState(bool);
void ToggleMasterState();
void HandleEncoderClick();
void HandleEncoderPosition();
void UpdateSpeedFactor();
void HandleDisplay();
void HandleExternalClock();
void HandleCVInputs();
void HandleCVTarget(int, float, CVTarget);
void HandleOutputs();
void ClockPulse();
void InitializeTimer();
void UpdateParameters(LoadSaveParams);

// ----------------------------------------------

// Handle encoder button click
void HandleEncoderClick() {
    oldSwitchState = switchState;
    switchState = digitalRead(ENCODER_SW);
    if (switchState == 1 && oldSwitchState == 0) {
        lastEncoderUpdate = millis();
        displayRefresh = 1;
        if (menuMode == 0) {
            switch (menuItem) {
            case 1: // Set BPM
                menuMode = 1;
                break;
            case 2: // Toggle stopped state
                ToggleMasterState();
                break;
            case 3: // Set div1
                menuMode = 3;
                break;
            case 4: // Set div2
                menuMode = 4;
                break;
            case 5: // Set div3
                menuMode = 5;
                break;
            case 6: // Set div4
                menuMode = 6;
                break;
            case 7: // External clock divider
                menuMode = 7;
                break;
            case 8: // Toggle output 1
                outputs[0].ToggleOutputState();
                unsavedChanges = true;
                break;
            case 9: // Toggle output 2
                outputs[1].ToggleOutputState();
                unsavedChanges = true;
                break;
            case 10: // Toggle output 3
                outputs[2].ToggleOutputState();
                unsavedChanges = true;
                break;
            case 11: // Toggle output 4
                outputs[3].ToggleOutputState();
                unsavedChanges = true;
                break;
            case 12: // Set pulse probability for output 1
                menuMode = 12;
                break;
            case 13: // Set pulse probability for output 2
                menuMode = 13;
                break;
            case 14: // Set pulse probability for output 3
                menuMode = 14;
                break;
            case 15: // Set pulse probability for output 4
                menuMode = 15;
                break;
            case 16: // Select Euclidean rhythm output to edit
                menuMode = 16;
                break;
            case 17: // Toggle Euclidean rhythm for output
                outputs[euclideanOutputSelect].ToggleEuclidean();
                unsavedChanges = true;
                break;
            case 18: // Set Euclidean rhythm step length
                menuMode = 18;
                break;
            case 19: // Set Euclidean rhythm number of triggers
                menuMode = 19;
                break;
            case 20: // Set Euclidean rhythm rotation
                menuMode = 20;
                break;
            case 21: // Set euclidean padding
                menuMode = 21;
                break;
            case 22: // Set swing amount for output 1
                menuMode = 22;
                break;
            case 23: // Set swing every for output 1
                menuMode = 23;
                break;
            case 24: // Set swing amount for output 2
                menuMode = 24;
                break;
            case 25: // Set swing every for output 2
                menuMode = 25;
                break;
            case 26: // Set swing amount for output 3
                menuMode = 26;
                break;
            case 27: // Set swing every for output 3
                menuMode = 27;
                break;
            case 28: // Set swing amount for output 4
                menuMode = 28;
                break;
            case 29: // Set swing every for output 4
                menuMode = 29;
                break;
            case 30: // Set phase shift for output 1
                menuMode = 30;
                break;
            case 31: // Set phase shift for output 2
                menuMode = 31;
                break;
            case 32: // Set phase shift for output 3
                menuMode = 32;
                break;
            case 33: // Set phase shift for output 4
                menuMode = 33;
                break;
            case 34: // Duty Cycle for output 1
                menuMode = 34;
                break;
            case 35: // Duty Cycle for output 2
                menuMode = 35;
                break;
            case 36: // Duty Cycle for output 3
                menuMode = 36;
                break;
            case 37: // Duty Cycle for output 4
                menuMode = 37;
                break;
            case 38: // Level control for output 3
                menuMode = 38;
                break;
            case 39: // Level offset for output 3
                menuMode = 39;
                break;
            case 40: // Level control for output 4
                menuMode = 40;
                break;
            case 41: // Level offset for output 4
                menuMode = 41;
                break;
            case 42: // Set Waveform type for output 3
                menuMode = 42;
                break;
            case 43: // Set Waveform type for output 4
                menuMode = 43;
                break;
            case 44: // Envelope output selection
                menuMode = 44;
                break;
            case 45: // Envelope attack time
                menuMode = 45;
                break;
            case 46: // Envelope decay time
                menuMode = 46;
                break;
            case 47: // Envelope sustain level
                menuMode = 47;
                break;
            case 48: // Envelope release time
                menuMode = 48;
                break;
            case 49: // Envelope curve
                menuMode = 49;
                break;
            case 50: // Envelope retrigger toggle
                outputs[envelopeOutputSelect].ToggleRetrigger();
                unsavedChanges = true;
                break;
            case 51: // CV Input 1 target
                if (menuMode == 51) {
                    pendingCVInputTarget[0] = CVInputTarget[0];
                }
                menuMode = 51;
                break;
            case 52: // CV Input 2 target
                if (menuMode == 52) {
                    pendingCVInputTarget[1] = CVInputTarget[1];
                }
                menuMode = 52;
                break;
            case 53: // CV Input 1 attenuation
                menuMode = 53;
                break;
            case 54: // CV Input 1 offset
                menuMode = 54;
                break;
            case 55: // CV Input 2 attenuation
                menuMode = 55;
                break;
            case 56: // CV Input 2 offset
                menuMode = 56;
                break;
            case 57: // Quantizer Output
                menuMode = 57;
                break;
            case 58: // Quantizer Enable
                outputs[quantizerOutputSelect].ToggleQuantizer();
                unsavedChanges = true;
                break;
            case 59: // Quantizer root note
                menuMode = 59;
                break;
            case 60: // Quantizer scale
                menuMode = 60;
                break;
            case 61: // Quantizer octave shift
                menuMode = 61;
                break;
            case 62: // Tap tempo
                SetTapTempo();
                break;
            case 63: // Select save slot
                menuMode = 63;
                break;
            case 64: { // Save settings
                LoadSaveParams p;
                p.valid = true;
                p.BPM = BPM;
                p.externalClockDivIdx = externalDividerIndex;
                for (int i = 0; i < NUM_OUTPUTS; i++) {
                    p.divIdx[i] = outputs[i].GetDividerIndex();
                    p.dutyCycle[i] = outputs[i].GetDutyCycle();
                    p.outputState[i] = outputs[i].GetOutputState();
                    p.outputLevel[i] = outputs[i].GetLevel();
                    p.outputOffset[i] = outputs[i].GetOffset();
                    p.swingIdx[i] = outputs[i].GetSwingAmountIndex();
                    p.swingEvery[i] = outputs[i].GetSwingEvery();
                    p.pulseProbability[i] = outputs[i].GetPulseProbability();
                    p.euclideanParams[i] = outputs[i].GetEuclideanParams();
                    p.phaseShift[i] = outputs[i].GetPhase();
                    p.waveformType[i] = int(outputs[i].GetWaveformType());
                    p.envParams[i] = outputs[i].GetEnvelopeParams();
                    p.quantizerParams[i] = outputs[i].GetQuantizerParams();
                }
                for (int i = 0; i < NUM_CV_INS; i++) {
                    p.CVInputTarget[i] = CVInputTarget[i];
                    p.CVInputAttenuation[i] = CVInputAttenuation[i];
                    p.CVInputOffset[i] = CVInputOffset[i];
                }

                Save(p, saveSlot);
                unsavedChanges = false;
                display.clearDisplay(); // clear display
                display.setTextSize(2);
                display.setCursor(SCREEN_WIDTH / 2 - 30, SCREEN_HEIGHT / 2 - 16);
                display.print("SAVED");
                display.display();
                unsigned long saveMessageStartTime = millis();
                while (millis() - saveMessageStartTime < 1000) {
                    HandleIO();
                }
                break;
            }
            case 65: { // Load from slot
                LoadSaveParams p = Load(saveSlot);
                UpdateParameters(p);
                unsavedChanges = false;
                display.clearDisplay(); // clear display
                display.setTextSize(2);
                display.setCursor(SCREEN_WIDTH / 2 - 30, SCREEN_HEIGHT / 2 - 16);
                display.print("LOADED");
                display.display();
                unsigned long loadMessageStartTime = millis();
                while (millis() - loadMessageStartTime < 1000) {
                    HandleIO();
                }
                break;
            }
            case 66: { // Load default settings
                LoadSaveParams p = LoadDefaultParams();
                UpdateParameters(p);
                unsavedChanges = false;
                display.clearDisplay(); // clear display
                display.setTextSize(2);
                display.setCursor(SCREEN_WIDTH / 2 - 30, SCREEN_HEIGHT / 2 - 16);
                display.print("LOADED");
                display.display();
                unsigned long loadMessageStartTime = millis();
                while (millis() - loadMessageStartTime < 1000) {
                    HandleIO();
                }
                break;
            }
            }
        } else {
            // Commit changes after exiting edit mode
            if (menuMode == 51) {
                CVInputTarget[0] = pendingCVInputTarget[0];
            } else if (menuMode == 52) {
                CVInputTarget[1] = pendingCVInputTarget[1];
            }
            // Exit edit mode
            menuMode = 0;
        }
    }
}

// Calculate the speed of the encoder rotation
float speedFactor;
unsigned long lastEncoderTime = 0;
void UpdateSpeedFactor() {
    unsigned long currentEncoderTime = millis();
    unsigned long timeDiff = currentEncoderTime - lastEncoderTime;
    lastEncoderTime = currentEncoderTime;

    if (timeDiff < 50) {
        speedFactor = 8.0; // Fast rotation
    } else if (timeDiff < 100) {
        speedFactor = 4.0; // Medium rotation
    } else if (timeDiff < 200) {
        speedFactor = 2.0; // Slow rotation
    } else {
        speedFactor = 1.0; // Normal rotation
    }
}
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
void loop() {
    HandleIO();

    // Only handle display every few frames
    if (frameSkip == 0) {
        HandleDisplay();
    }
    frameSkip = (frameSkip + 1) % FRAME_SKIP_COUNT;
}

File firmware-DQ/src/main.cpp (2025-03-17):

#include <Arduino.h>

// Rotary encoder setting
#define ENCODER_OPTIMIZE_INTERRUPTS // counter measure of noise
#include <Encoder.h>

#include <Adafruit_GFX.h>
#include <Adafruit_SSD1306.h>

// Load local libraries
#include "boardIO.cpp"
#include "loadsave.cpp"
#include "pinouts.hpp"
#include "quantizer.cpp"
#include "scales.cpp"
#include "splash.hpp"
#include "version.hpp"

// ADC Calibration settings
const int ADC_THRESHOLD = 5; // Threshold for ADC stability
// float ADCCal[2] = {1.026, 1.026}; // ADC readings for the channels
// int ADCOffset[2] = {25, 25};      // ADC offset for the channels
float ADCCal[2] = {1.0180, 1.0180}; // ADC readings for the channels
int ADCOffset[2] = {23, 23};        // ADC offset for the channels
////////////////////////////////////////////

#define OLED_ADDRESS 0x3C
#define SCREEN_WIDTH 128
#define SCREEN_HEIGHT 64
// OLED display initialization
Adafruit_SSD1306 display(SCREEN_WIDTH, SCREEN_HEIGHT, &Wire, -1);

// Rotary encoder initialization
Encoder encoder(ENC_PIN_1, ENC_PIN_2); // rotary encoder library setting
float oldPosition = -999;              // rotary encoder library setting
float newPosition = -999;              // rotary encoder library setting

int menuItems = 38; // Amount of menu items
int menuItem = 1;   // Current position of the encoder

bool switchState = 1;    // Encoder switch state
bool oldSwitchState = 1; // Encoder switch state on last cycle
bool clockInput = 0;     // Clock input state
bool oldClockInput = 0;  // Clock input state on last cycle
int menuMode = 0;        // 0=select,1=atk[0],2=dcy[0],3=atk[1],4=dcy[1], 5=scale, 6=note

// ADC input variables
float channelADC[2], oldChannelADC[2];
int quantizedNoteIdx[2], oldQuantizedNoteIdx[2] = {0, 0};

float CVOutput[2], oldCVOutput[2] = {0, 0}; // CV output
long gateTimer[2] = {0, 0};                 // EG curve progress speed

// envelope curve setting
int ADEnvelopeTable[200] = { // envelope table
    0, 15, 30, 44, 59, 73, 87, 101, 116, 130, 143, 157, 170, 183, 195, 208, 220, 233, 245, 257, 267, 279, 290, 302, 313, 324, 335, 346, 355, 366, 376, 386, 397, 405, 415, 425, 434, 443, 452, 462, 470, 479, 488, 495, 504, 513, 520, 528, 536, 544, 552, 559, 567, 573, 581, 589, 595, 602, 609, 616, 622, 629, 635, 642, 648, 654, 660, 666, 672, 677, 683, 689, 695, 700, 706, 711, 717, 722, 726, 732, 736, 741, 746, 751, 756, 760, 765, 770, 774, 778, 783, 787, 791, 796, 799, 803, 808, 811, 815, 818, 823, 826, 830, 834, 837, 840, 845, 848, 851, 854, 858, 861, 864, 866, 869, 873, 876, 879, 881, 885, 887, 890, 893, 896, 898, 901, 903, 906, 909, 911, 913, 916, 918, 920, 923, 925, 927, 929, 931, 933, 936, 938, 940, 942, 944, 946, 948, 950, 952, 954, 955, 957, 960, 961, 963, 965, 966, 968, 969, 971, 973, 975, 976, 977, 979, 980, 981, 983, 984, 986, 988, 989, 990, 991, 993, 994, 995, 996, 997, 999, 1000, 1002, 1003, 1004, 1005, 1006, 1007, 1008, 1009, 1010, 1012, 1013, 1014, 1014, 1015, 1016, 1017, 1018, 1019, 1020};

int adcValues[2] = {0, 0}; // PWM DUTY reference
bool ADTrigger[2] = {0, 0};
u_int8_t attackEnvelope[2], decayEnvelope[2]; // attack time,decay time
u_int8_t syncSignal[2];                       // 0=sync with trig , 1=sync with note change
u_int8_t octaveShift[2];                      // oct=octave shift
u_int8_t channelSensitivity[2];               // sens = AD input attn,amp

// CV setting
int quantizerThresholdBuff[2][62]; // input quantize

// Scale and Note loading indexes
int scaleIndex = 1;
int noteIndex = 0;

// Note Storage
bool activeNotes[2][12] = {{false}}; // 1=note valid,0=note invalid

// display
bool displayRefresh = 1;     // 0=not refresh display , 1= refresh display , countermeasure of display refresh busy
bool unsavedChanges = false; // Unsaved changes flag

// Function prototypes
void HandleEncoderPosition();
void HandleEncoderClick();
void HandleInputs();
void HandleOutputs();
void HandleIO();
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

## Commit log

2024-06-28 Integrate project with PlatformIO config
    [control_pcb_v1_1.kicad_pcb, main_pcb.kicad_pcb]
2024-06-28 Refactor quantize buffer assembly
2024-06-30 Typos, add DAC pin define
2024-07-18 Fix output clock generation on CLK
    [main.cpp]
2024-07-18 Update BOM. Add some documentation details.
    [BOM.csv]
2024-10-28 CLK - Fix issues, still problem with external DAC output
    [main.cpp]
2024-10-28 CLK - Rewrite without the uClock lib. Fix DAC out.
    [main.cpp]
2024-10-28 Fix quantizer calibration
2024-10-28 Better calibration instructions
2024-10-30 Fixes for quantizer. Code cleanup.
    [main.cpp]
2024-10-30 Fix quantize buffer build. Rename vars and dedup code
    [main.cpp]
2024-10-30 Reformat using Google CPP style (same line brackets)
2024-10-31 Reset outputs to keep in sync after div changes
    [main.cpp]
2024-11-01 Fix external clock sync
    [main.cpp]
2024-11-04 Fence time sensitive code from interrupts
2024-11-04 Fix and improve external clock sync
    [main.cpp]
2024-11-05 DQ - Fix note loading. Code cleanup.
    [main.cpp]
2024-11-13 CLK - Dirty hack to update display. Temp fix...
    [main.cpp]
2024-11-18 Fix parameter load/save and master pause
    [main.cpp, outputs.hpp]
2024-11-18 Refactor play/stop. Fix menu indexing.
    [main.cpp, outputs.hpp]
2024-11-19 Organize files, add logo
    [BOM.csv, control_pcb_v1_1.kicad_pcb, main_pcb.kicad_pcb]
2024-11-19 Fix the dividers when using external clocks
    [main.cpp, outputs.hpp]
2024-11-20 Fix menu indexing (again)...
    [main.cpp]
2024-11-21 CLK - Add encoder acceleration factors
2024-11-22 CLK - Revert to uppercase font
    [main.cpp]
2024-11-30 Start at the correct menu item
    [main.cpp]
2024-12-04 Fix menu indexing, remove acceleration
    [main.cpp]
2024-12-05 CLK - Add multiple load/save slots
2024-12-05 CLK - Better smooth noise but not good yet
    [outputs.hpp]
2024-12-05 CLK - Fix divisors on external clock (probability still broken)
    [main.cpp, outputs.hpp]
2024-12-10 CLK - Fix swing since it's indexed in 96ths
    [outputs.hpp]
2024-12-10 DQ - Add calibration screen to avoid fixed params
    [main.cpp]
2024-12-10 CLK - Fix duty cycle for outputs 1 and 2
    [main.cpp, outputs.hpp]
2024-12-10 CLK - Fix sine wave duty and parabolic probability
    [outputs.hpp]
2024-12-10 CLK - Fix sine wave duty (finally) and better smooth noise generator
    [outputs.hpp]
2024-12-10 DQ - Pass display reference to calibrate screen
2024-12-17 CLK - Add dividers to main screen and reset to CV targets
    [main.cpp]
2024-12-18 CLK - GUI improvements. Eucl padding fix
    [main.cpp, outputs.hpp]
2024-12-18 CLK - Add Sample&Hold waveform where a random value is generated on each pulse
2024-12-19 DQ - Revert to manual calibration as it's more accurate
    [main.cpp]
2024-12-19 CLK - Revert to manual CV input calibration
    [main.cpp]
2025-01-29 New panel text
    [BOM-DQ-Panel.csv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]
2025-02-05 Rename random to noise waves
    [outputs.hpp]
2025-02-06 Fix release value, add retrigger option to envelopes
    [outputs.hpp]
2025-02-07 Fixes for envelopes. Revamp load/save.
    [main.cpp, outputs.hpp]
2025-02-07 Fix indicator arrow position
    [main.cpp]
2025-02-08 Rename Log and Exp envelopes to inverted
    [outputs.hpp]
2025-03-10 Add Play/Reset outputs. Reset counters on stop/start.
    [main.cpp, outputs.hpp]
2025-03-17 DQ - Remove unused calibration variable
2025-03-20 Fix play/reset outputs and exponential wave
    [outputs.hpp]
2025-03-24 Skip envelope multiplier for digital outs
    [outputs.hpp]
2025-05-02 Fixes saving dividers and reverting dividers from envelopes. Fix #32.
    [main.cpp, outputs.hpp]
2025-05-02 Add sample test files
2025-08-12 Update submodules to track main branch
